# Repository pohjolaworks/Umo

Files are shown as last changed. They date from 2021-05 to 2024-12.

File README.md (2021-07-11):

# Umō
*羽毛 (Umō)* - A top-mount 3D-printable case for Yasui PCB by Rainkeebs.
Name *Umō* comes from Japanese and means a "Quill" - A feather that is dipped in ink and used to write with.

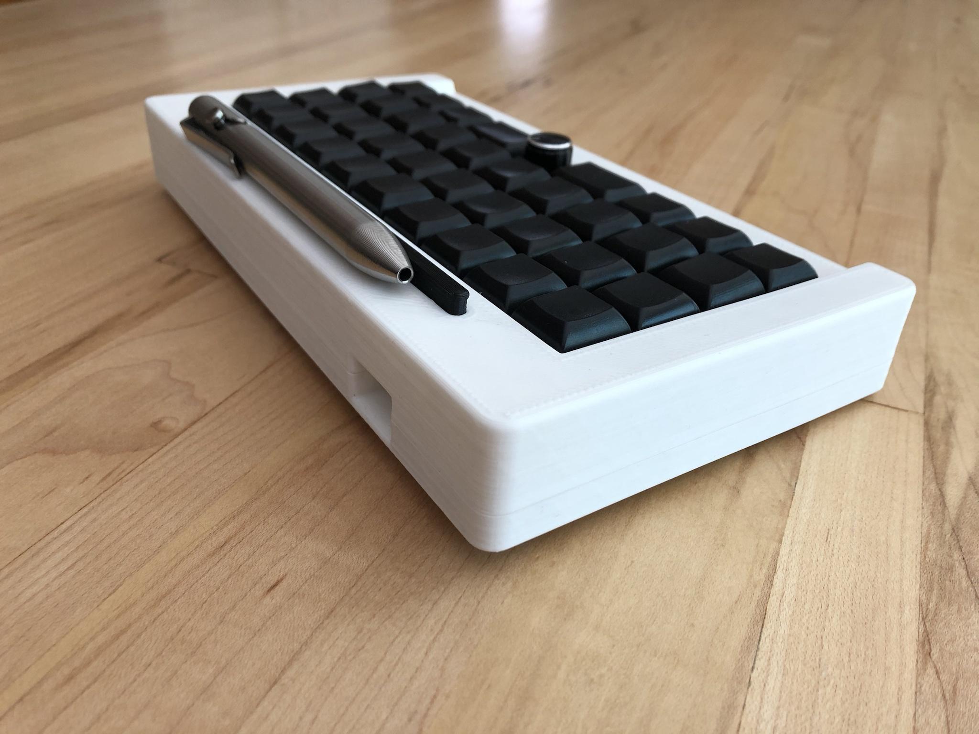
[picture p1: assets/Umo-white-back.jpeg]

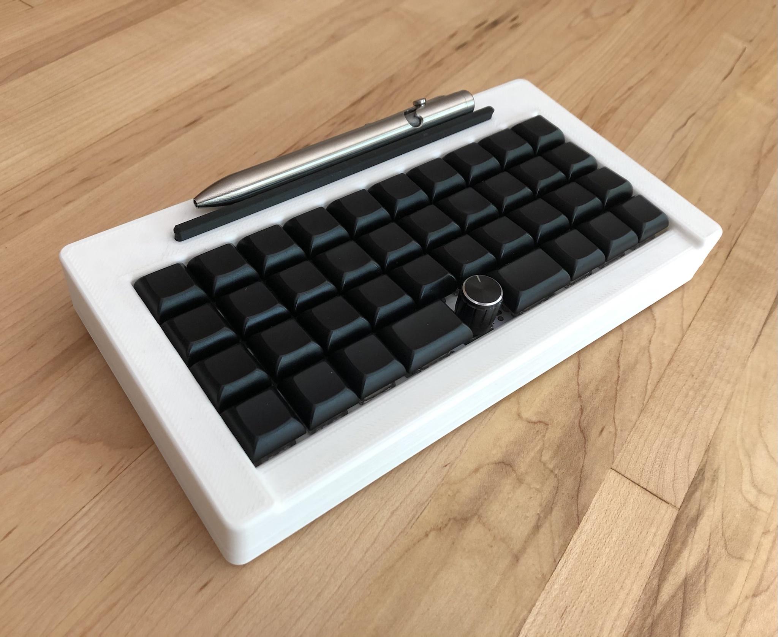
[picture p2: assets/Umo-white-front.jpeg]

[Imgur album](https://imgur.com/gallery/CjK1rLI)

This design is provided to the community completely free of charge, free of any liabilities and free to use by everyone !
Depending on your printer's calibration, you might not be able to get a good fit right away. So print at your own risk, and know your machine !
## Printing your Umō

If you want to get it right the first time, it is recommended to first print out ```test-fit piece.stl``` file found in ```STLs/Other parts/``` folder to test out
your fitment before committing to a full case print. The internal dimensions are sized exactly as the case itself, so if your PCB & plate fit right into the space inside the test piece, you should be good.

Plate STLs are included as well and they do work when 3D-printed, however you might get a better fitment & typing experience by sourcing a laser-cut POM/Acrylic plate or a FR4 1.6mm plate.

The case uses M2 heat inserts, that are melted into their mounting holes in the top piece. The plate and the bottom will then be installed into the top piece and fastened in place by M2 screws.
There are a few variations for you to print, so pick out the ones that you like, it's your case !

### Hardware & Parts list

1x Bottom (any variation)  
1x Top (any variation)   
1x Plate (any variation)  
1x Pen holder (normal or wide, depending on your top case)  
(optional) 1x Riser  
(optional) 4x Rubber bumpons (max 10mm diameter for bumpon mounts in the bottom)  

10x M2 heat inserts (max length ~3.5mm, longer ones might get clogged more easily)  
4x 3-6mm M2 screws for plate (depends on your plate thickness)  
6x 4-5mm M2 screws for bottom case  

## About

Designed by [Ergorius](https://github.com/ErkHal) and [KaeBoards](https://github.com/KaeBoards)

Huge thanks to suikahead for helping us out with the name and the kanji !

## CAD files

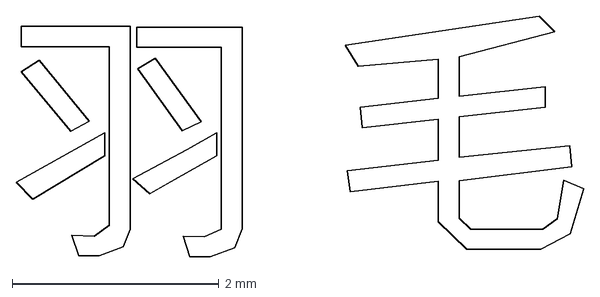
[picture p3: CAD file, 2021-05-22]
Plate files/FR4/KiCAD Project/Kanji.dxf
5.50 x 2.33 mm

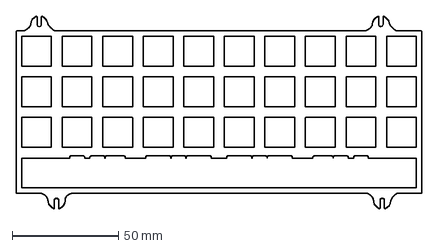
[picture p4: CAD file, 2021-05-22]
Plate files/Universal.dxf
190.5 x 90.3 mm

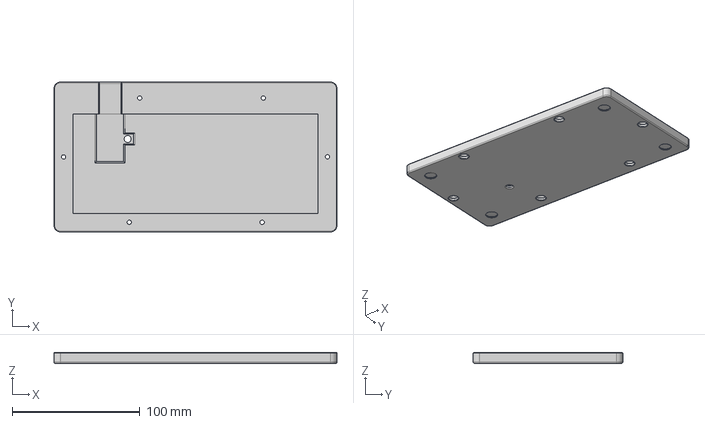
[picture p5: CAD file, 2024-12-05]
STEPs/Bottom/Bottom case (bumpon mounts).step
221.5 x 117.2 x 8.50 mm

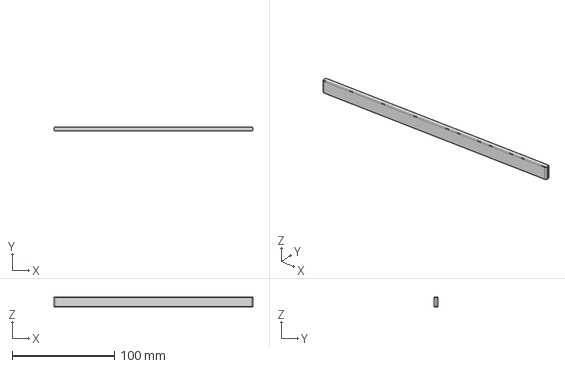
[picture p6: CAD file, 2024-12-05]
STEPs/Other parts/Pen holder - Wide.step
194.5 x 4.00 x 10.0 mm

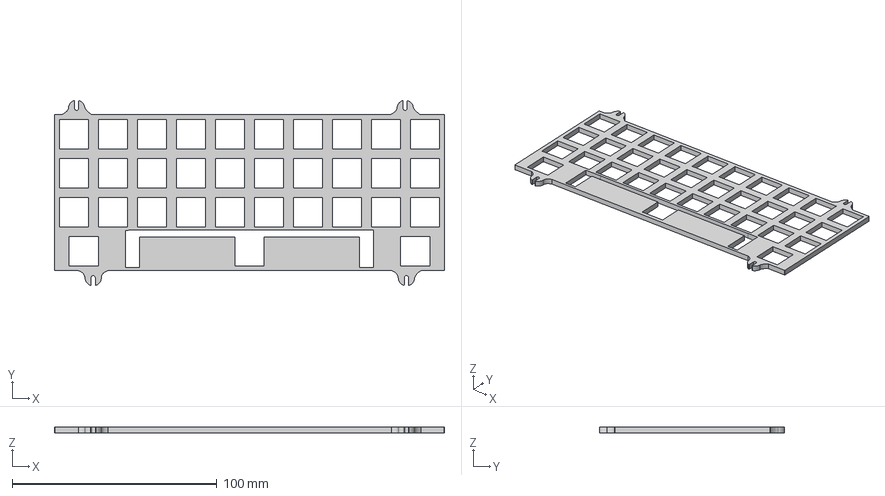
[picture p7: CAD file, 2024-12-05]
STEPs/Plates/7U plate 3mm plate.step
190.5 x 90.3 x 3.00 mm

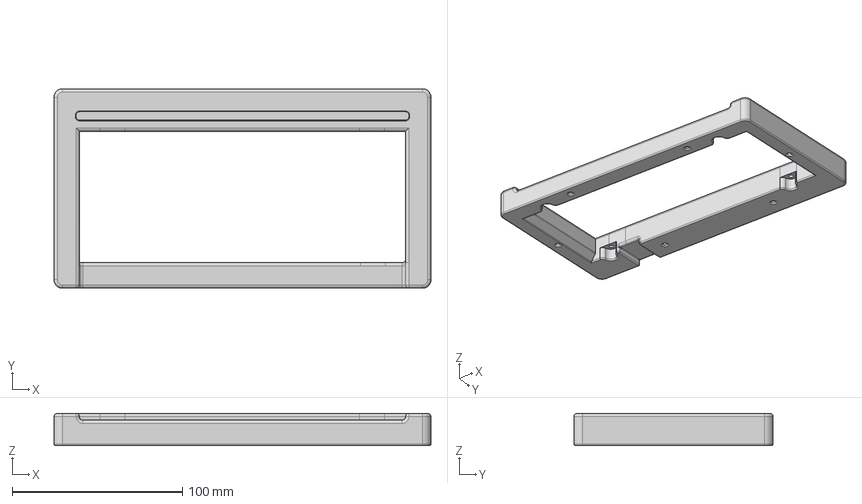
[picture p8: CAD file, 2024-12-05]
STEPs/Top - Wider pen holder/Top case - Groove.step
221.5 x 117.2 x 19.0 mm

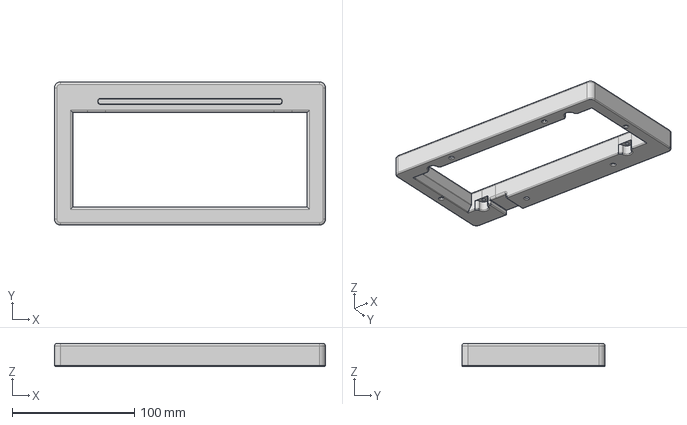
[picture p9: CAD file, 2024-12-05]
STEPs/Top/Top case flat.step
221.5 x 117.2 x 19.0 mm

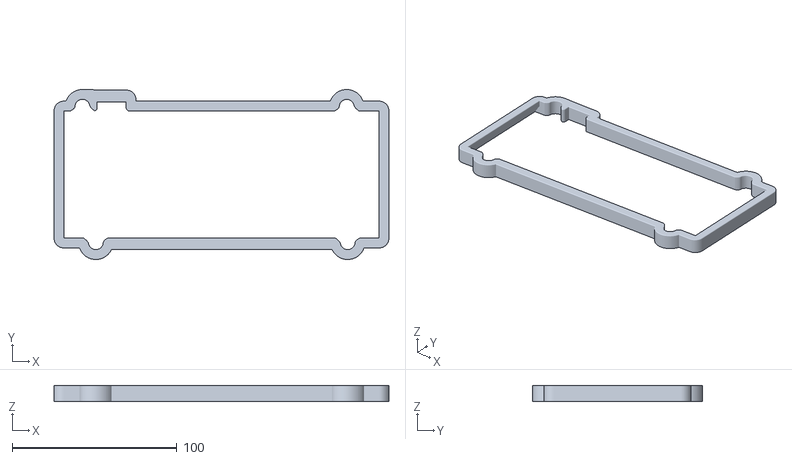
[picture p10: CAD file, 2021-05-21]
STLs/Other parts/Test-fit piece.stl
203.5 x 103.3 x 10.0

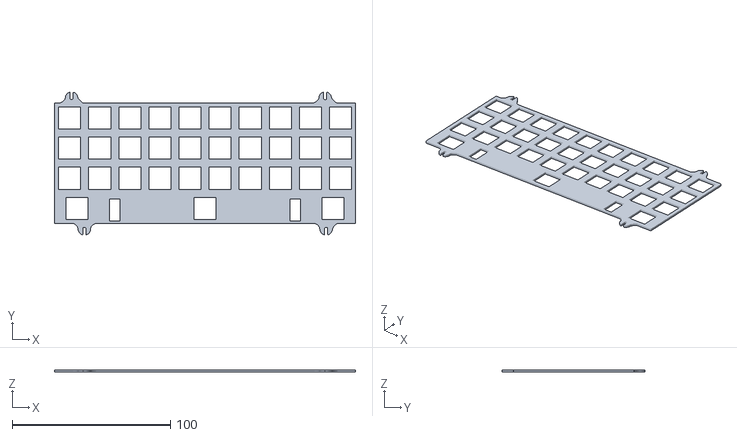
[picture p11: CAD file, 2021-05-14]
STLs/Plates/7U.stl
190.5 x 90.3 x 1.50

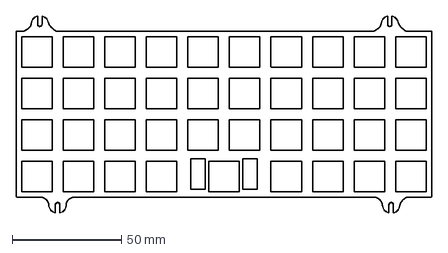
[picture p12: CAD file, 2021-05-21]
Plate files/1x 2U.dxf
190.5 x 90.3 mm

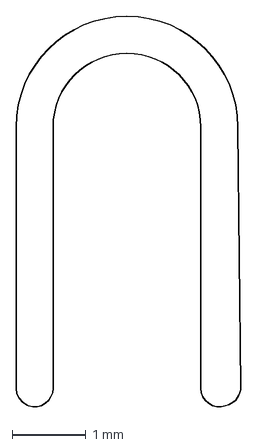
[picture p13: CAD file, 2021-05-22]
Plate files/FR4/KiCAD Project/Mounting point copper fill.dxf
3.04 x 5.30 mm

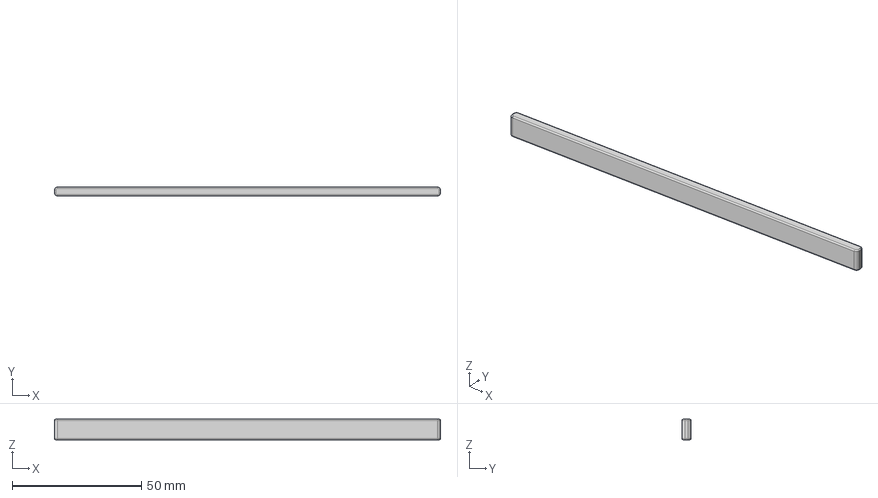
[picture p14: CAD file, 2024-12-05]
STEPs/Other parts/Pen holder - short.step
149.5 x 3.50 x 8.00 mm

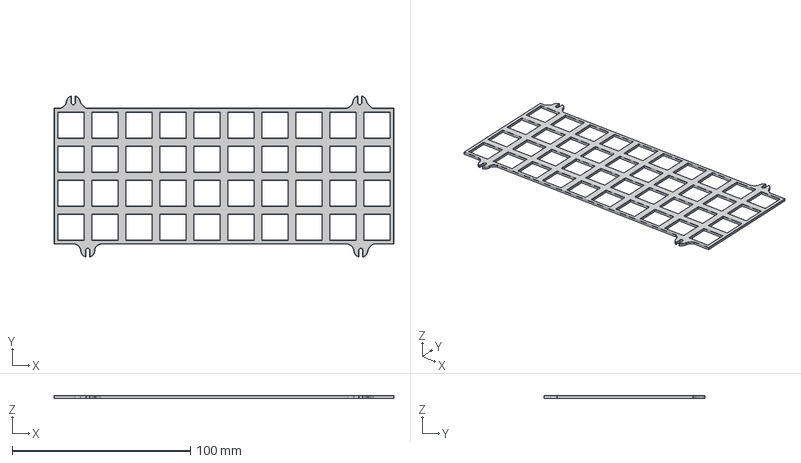
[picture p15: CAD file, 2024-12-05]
STEPs/Plates/1U grid plate.step
190.5 x 90.3 x 1.50 mm

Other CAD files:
STLs/Bottom/Bottom - bumpon mounts.stl
STLs/Top - Wider pen holder/Grooved - Wider pen holder.stl
STLs/Top/Flat.stl
STEPs/Bottom/Bottom - Kanji.step
STEPs/Top - Wider pen holder/Top case flat.step
Plate files/1u Grid.dxf
Plate files/2U or 2x 2U 3mm plate.dxf
Plate files/2x 2U.dxf
Plate files/FR4/KiCAD Project/Mounting point solder mask.dxf
Plate files/FR4/KiCAD Project/Universal.dxf
Plate files/Fixed 7u - 3mm.dxf
Plate files/Fixed 7u.dxf
STEPs/Bottom/Bottom case.step
STEPs/Other parts/Riser.step
STEPs/Plates/7U plate 1.5mm.step
STEPs/Plates/Universal plate.step
STEPs/Top/Top case - groove.step
STLs/Bottom/Bottom - bumpon mounts - kanji.stl
STLs/Bottom/Flat - kanji.stl
STLs/Bottom/Flat.stl
STLs/Other parts/Pen holder.stl
STLs/Other parts/Riser.stl
STLs/Other parts/Wider pen holder.stl
STLs/Plates/1U Grid.stl
STLs/Plates/7U - 3mm.stl
STLs/Plates/Universal.stl
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

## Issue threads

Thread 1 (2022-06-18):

solid body files?

hanhanhan-kim, 2022-06-18:
Hello! This case is very beautiful. I was wondering if it might be possible to release the solid body files (e.g. `.step`) for easier modification of the case? I would be interested in modifying this case for similar boards, like the Planck and the Preonic. Thanks very much!

ErkHal, 2024-12-05:
@hanhanhan-kim I've now uploaded the STEP files, they are located in the `STEPs` folder. Sorry for this taking so long to notice this issue !

Closed 2024-12-05.

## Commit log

2021-05-14 Initial revision
    [1U Grid.stl, 7U - 3mm.stl, 7U.stl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]
2021-05-18 Added chamfers to the top pieces for better pcb fitment.
2021-05-20 Add universal plate file, tweak top case heat insert holes
    [Universal.dxf]
2021-05-21 Add new test piece, update README with instructions & BOM
    [Test-fit piece.stl]
2021-05-21 Add filleted top pieces for easier fitment, export newest project
    [Flat - Wider pen holder.stl, Flat.stl, Grooved - Wider pen holder.stl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]
2021-05-21 Add plate files, add pics and link to album in README
    [1u Grid.dxf, 1x 2U.dxf, 2U or 2x 2U 3mm plate.dxf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]
2021-05-22 Add better universal plate file, push latest project file
    [Universal.dxf]
2021-05-22 Move new universal plate to right folder
    [Universal.dxf]
2021-05-22 Add FR4 plate KiCAD project and ready-made gerbers
    [Kanji.dxf, Mounting point copper fill.dxf, Mounting point solder mask.dxf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]
2021-05-22 Rename KiCAD project, add better gerbers
    [Umo FR4 Plates-B_Mask.gbr, Umo FR4 Plates-B_Paste.gbr, Umo FR4 Plates-B_SilkS.gbr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]
2024-12-05 Add STEP files
    [1U grid plate.step, 7U plate 1.5mm.step, 7U plate 3mm plate.step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]
